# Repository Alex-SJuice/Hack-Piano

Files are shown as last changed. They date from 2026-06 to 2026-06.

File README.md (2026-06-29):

# Hack Piano

A Hackpad, in the form of a piano!

It can serve as a normal macropad too.

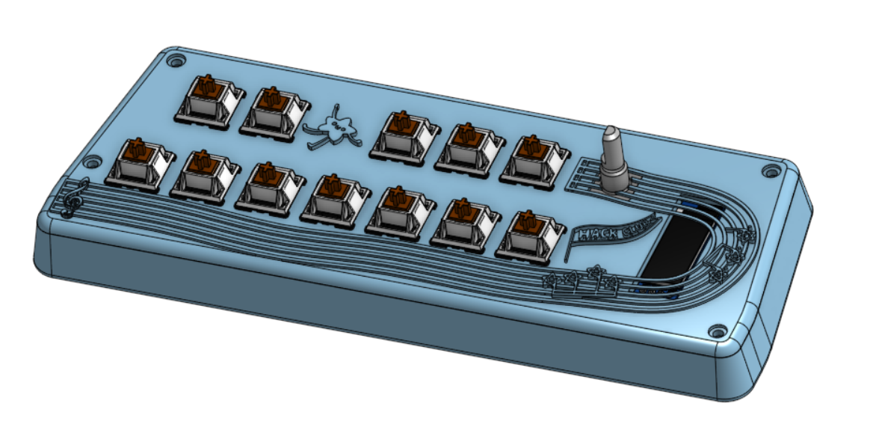
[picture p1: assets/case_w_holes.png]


## Motivation

I've wanted a MIDI keyboard for a while, and I thought this would be a decent substitute (and a fun challenge!).

This is my first ever project I've made from start to finish, with my own design, so It's very exciting!

I'm hoping to use the skills from this project in others, like my WIP 3d camera (shameless plug)

## Schematic & PCB

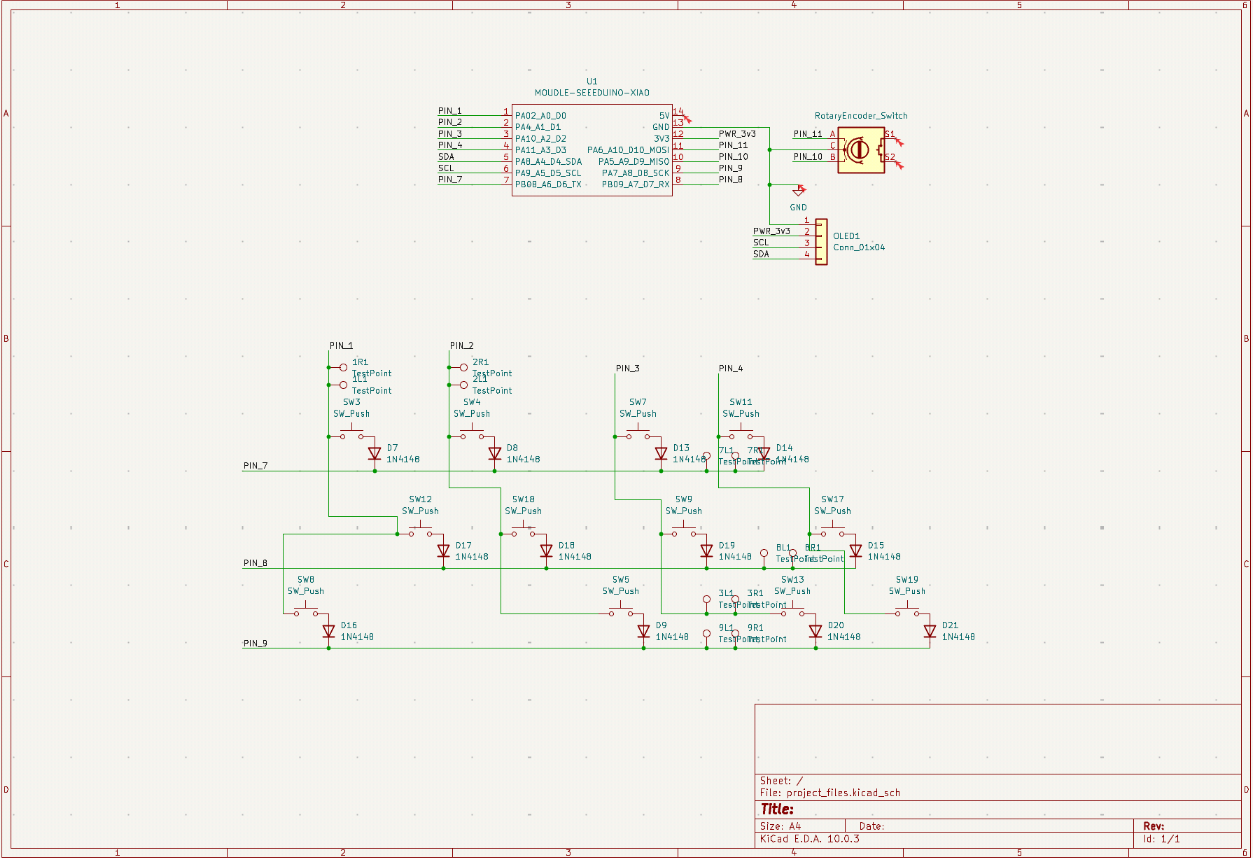
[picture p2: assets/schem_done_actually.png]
Schematic


It was difficult to align everything so the traces are nice, especially since I was forced to wire the keys in a 4x3 grid because of the number of pins

Another BIG problem was that the pcb was too wide. I decided to split the pcb in half and stack the two halves together to get the size requirements, then add breakpoints so I could assemble and solder the pcb together. Thanks to Anicetus for the idea!

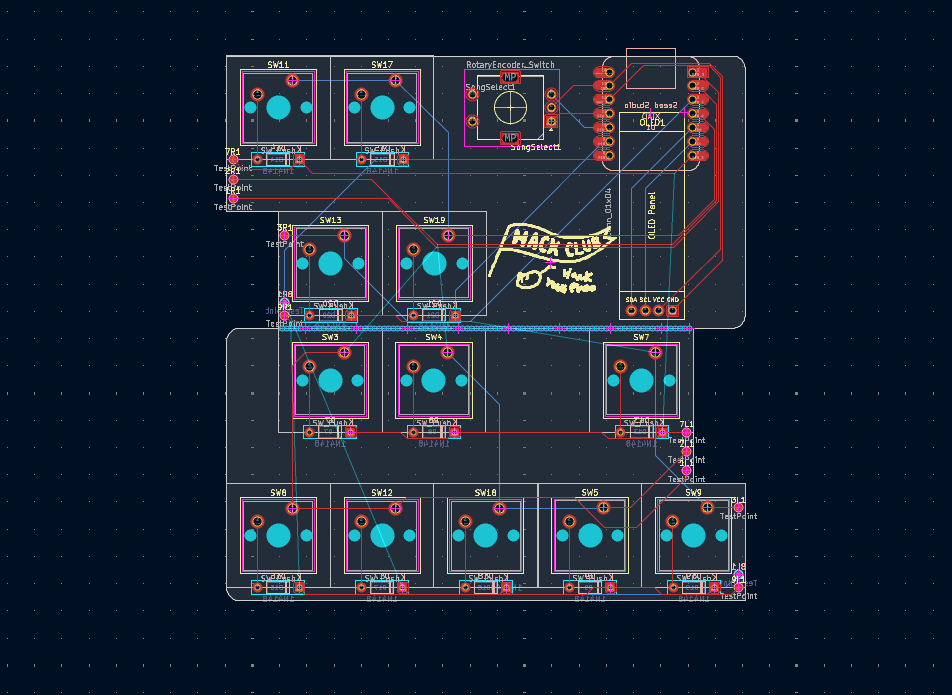
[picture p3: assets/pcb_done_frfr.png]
PCB


Final Shape:

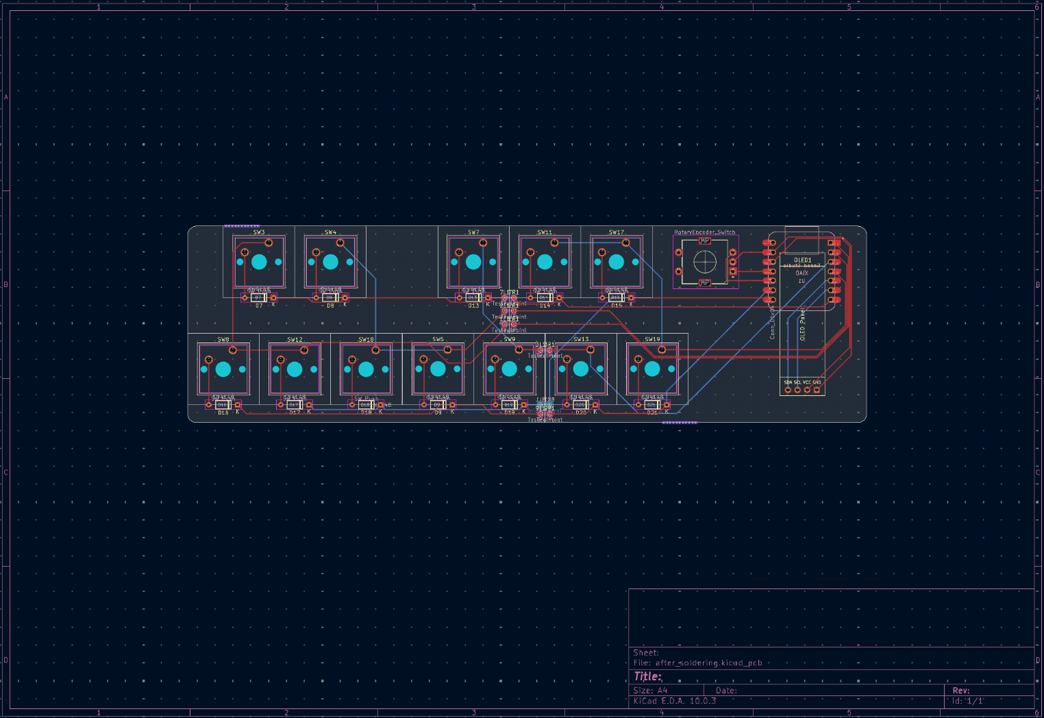
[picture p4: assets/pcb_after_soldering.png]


## Case

Oh my goodness, the case was actually horrible to work on. It mostly stems from the fact that I decided to make a bunch of small details that would be really annoying to change if say, the lid and base were different shapes the entire time. Also someone's got to burn the Onshape splines on a stake.

btw all of the overhangs are getting printed with supports (should I provide gcode in that case?)

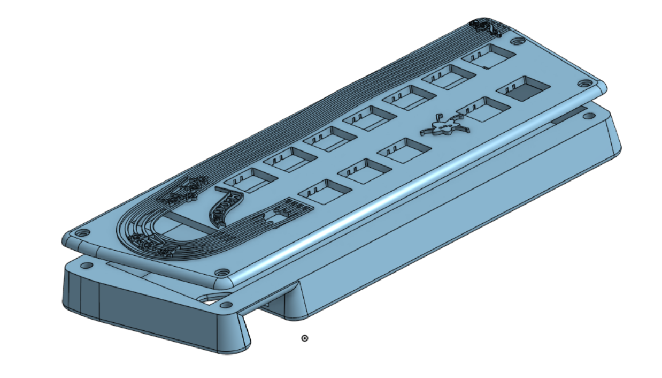
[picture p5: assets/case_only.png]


## BOM:
 - 12x Cherry MX Switches
 - 12x DSA Keycaps (optional but you can get 2u keys for the bottoms 7)
 - 4x M3x5x4 Heatset inserts
 - 4x M3x16mm screws
 - 12x 1N4148 DO-35 Diodes
 - 1x 0.91" 128x32 OLED Display
 - 1x EC11 Rotary Encoder
 - 1x XIAO RP2040
 - 1x Case (2 printed parts)

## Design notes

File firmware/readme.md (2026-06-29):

# hack_piano

*A Hackpad (courtesy of Hackclub), in the form of a piano!*

* Keyboard Maintainer: [Alex](https://github.com/Alex-SJuice)
* Hardware Supported: *The PCBs, controllers supported*
* Hardware Availability: *Links to where you can find this hardware*

Make example for this keyboard (after setting up your build environment):

    make hack_piano:default

Flashing example for this keyboard:

    make hack_piano:default:flash

See the [build environment setup](https://docs.qmk.fm/#/getting_started_build_tools) and the [make instructions](https://docs.qmk.fm/#/getting_started_make_guide) for more information. Brand new to QMK? Start with our [Complete Newbs Guide](https://docs.qmk.fm/#/newbs).

## Bootloader

Enter the bootloader in 3 ways:

* **Bootmagic reset**: Hold down the key at (0,0) in the matrix (usually the top left key or Escape) and plug in the keyboard
* **Physical reset button**: Briefly press the button on the back of the PCB - some may have pads you must short instead
* **Keycode in layout**: Press the key mapped to `QK_BOOT` if it is available

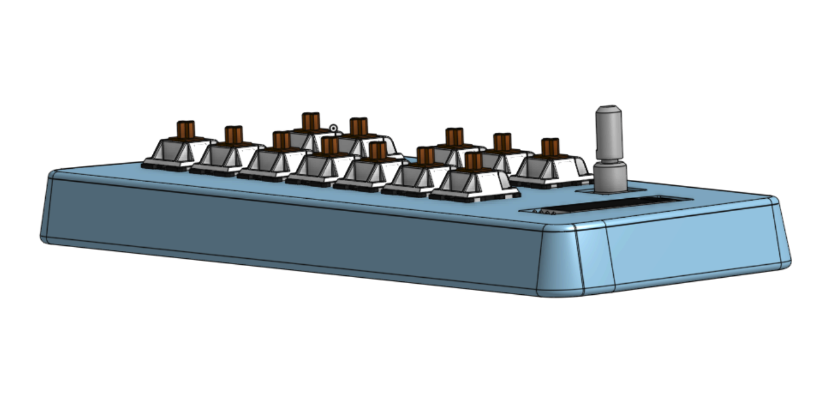
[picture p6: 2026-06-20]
assets/wip_pics/curved.png

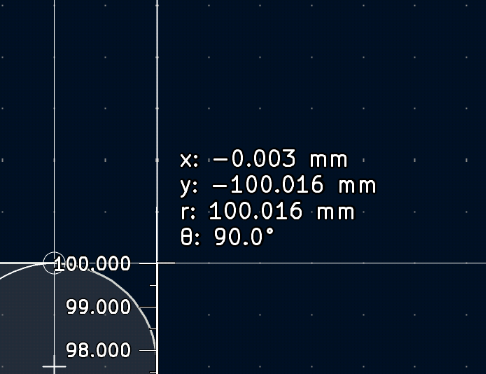
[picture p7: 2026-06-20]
assets/wip_pics/close.png

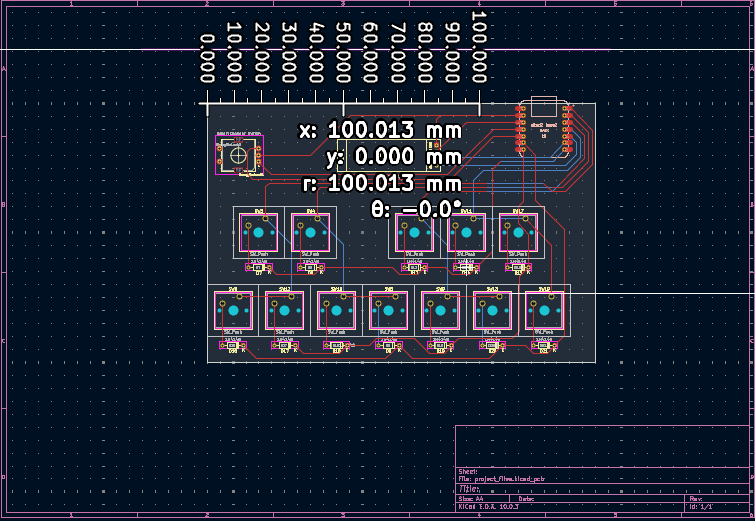
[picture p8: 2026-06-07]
assets/wip_pics/pcb_wip3.png

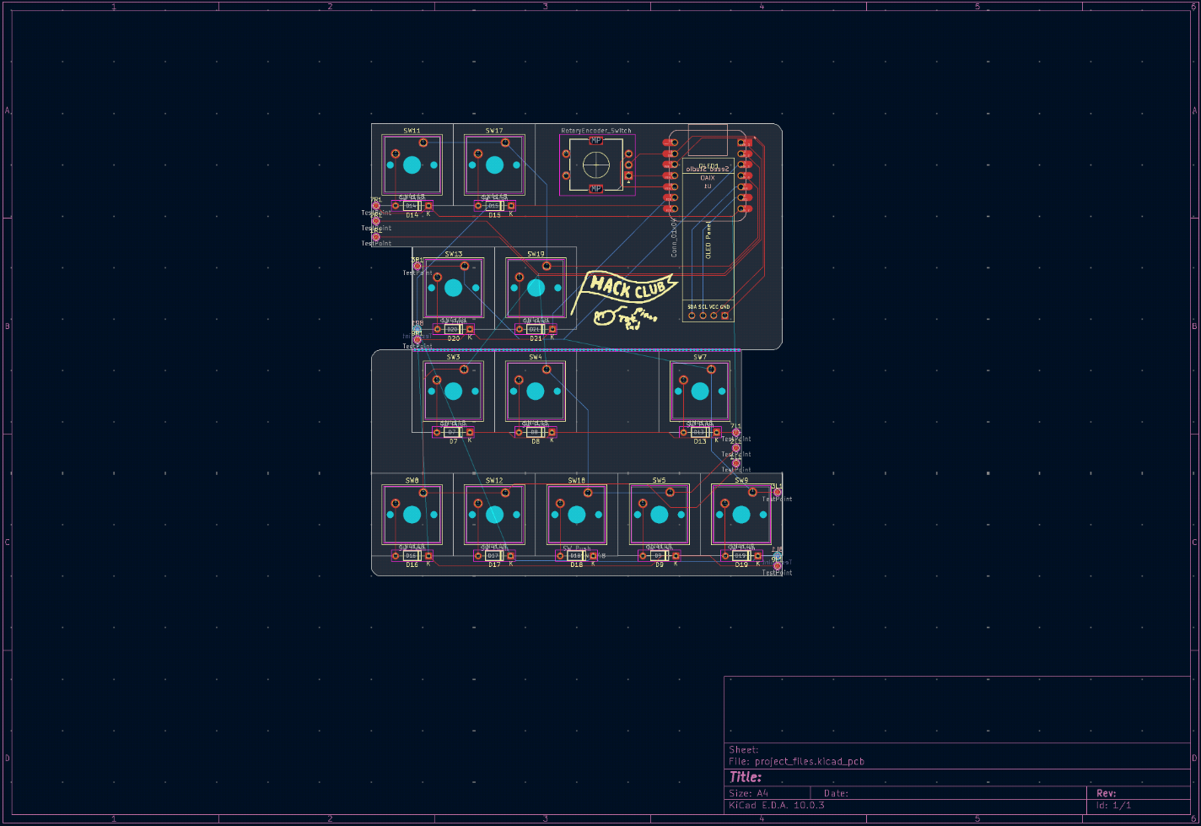
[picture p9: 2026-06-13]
assets/wip_pics/pcb_done_fr.png

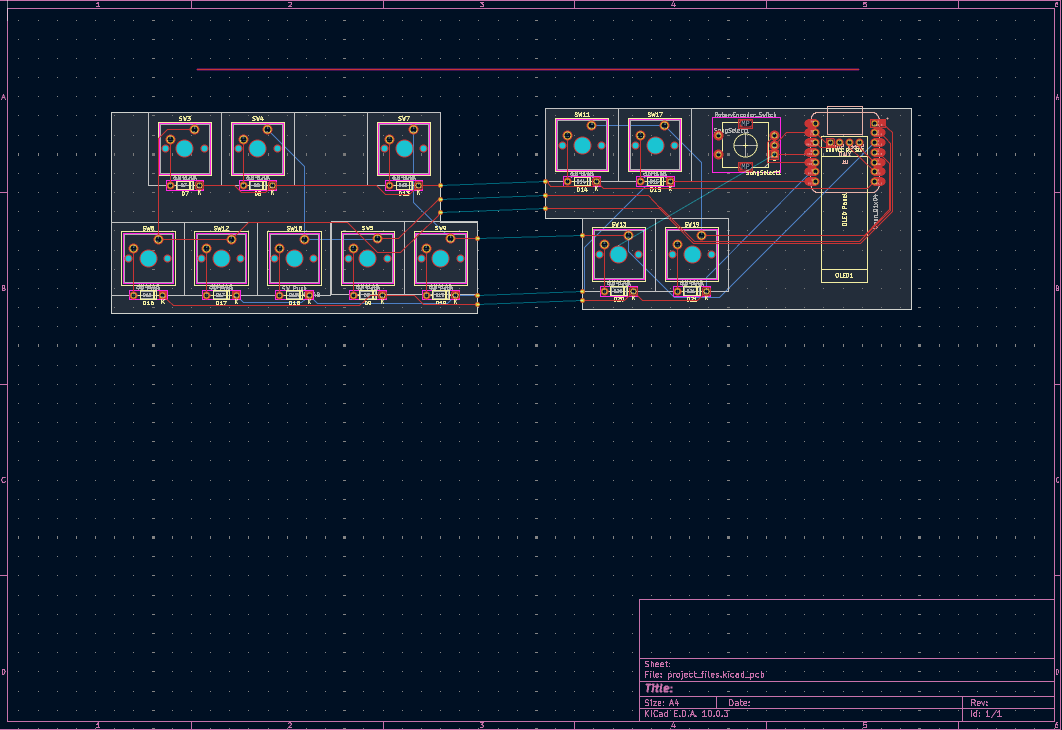
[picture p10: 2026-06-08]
assets/wip_pics/pcb_wip4.png

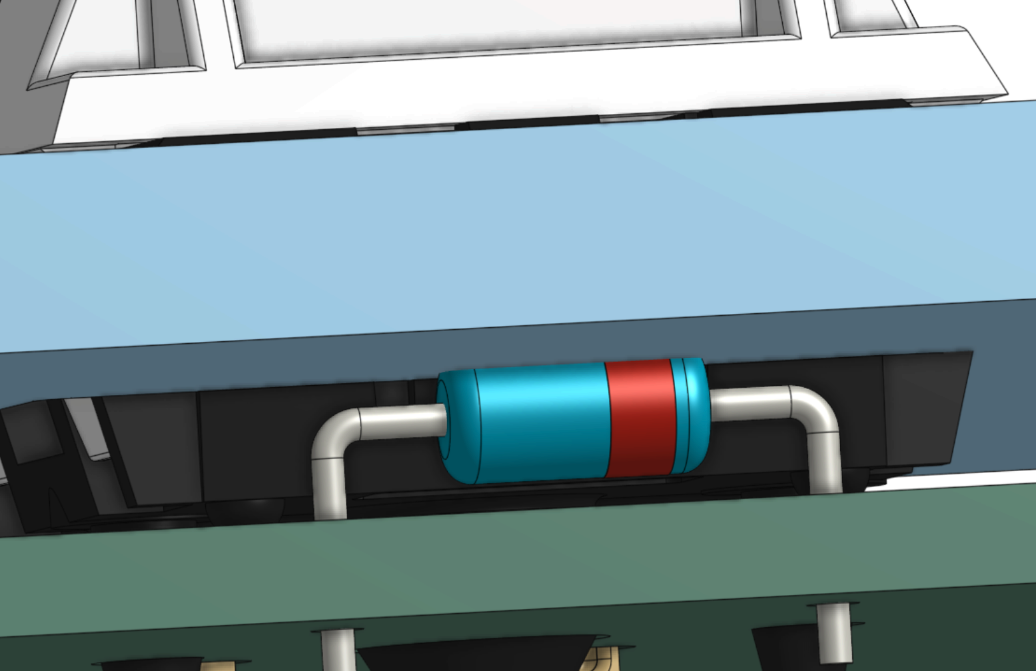
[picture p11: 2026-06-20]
assets/wip_pics/uhhhhhhh.png

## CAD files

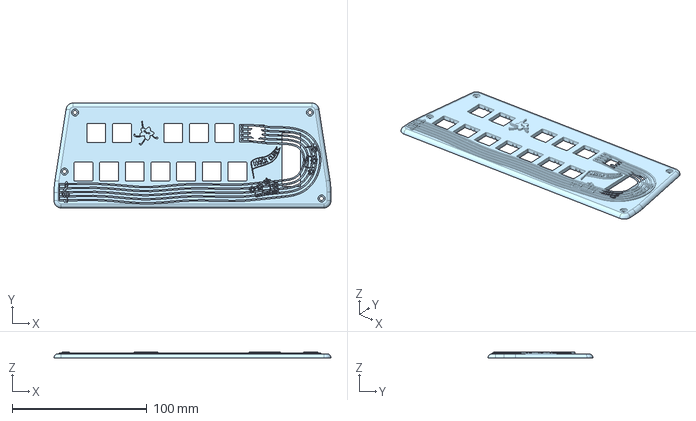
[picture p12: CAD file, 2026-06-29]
production/Lid.step
205.7 x 77.9 x 4.25 mm

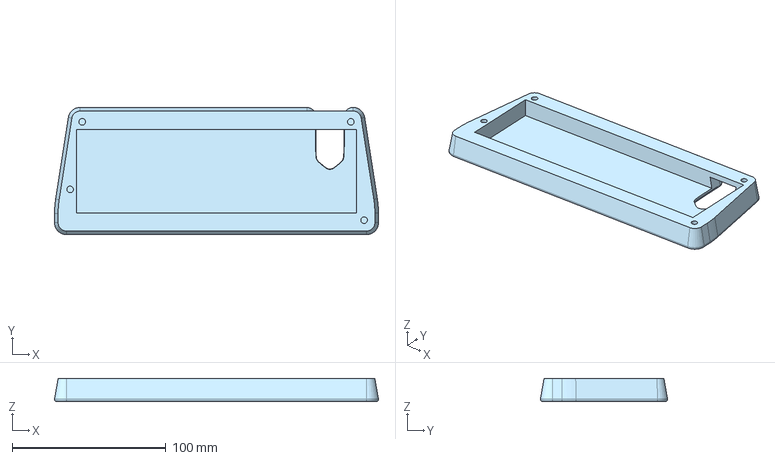
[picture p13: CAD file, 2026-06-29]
production/Base.step
210.4 x 82.6 x 15.0 mm

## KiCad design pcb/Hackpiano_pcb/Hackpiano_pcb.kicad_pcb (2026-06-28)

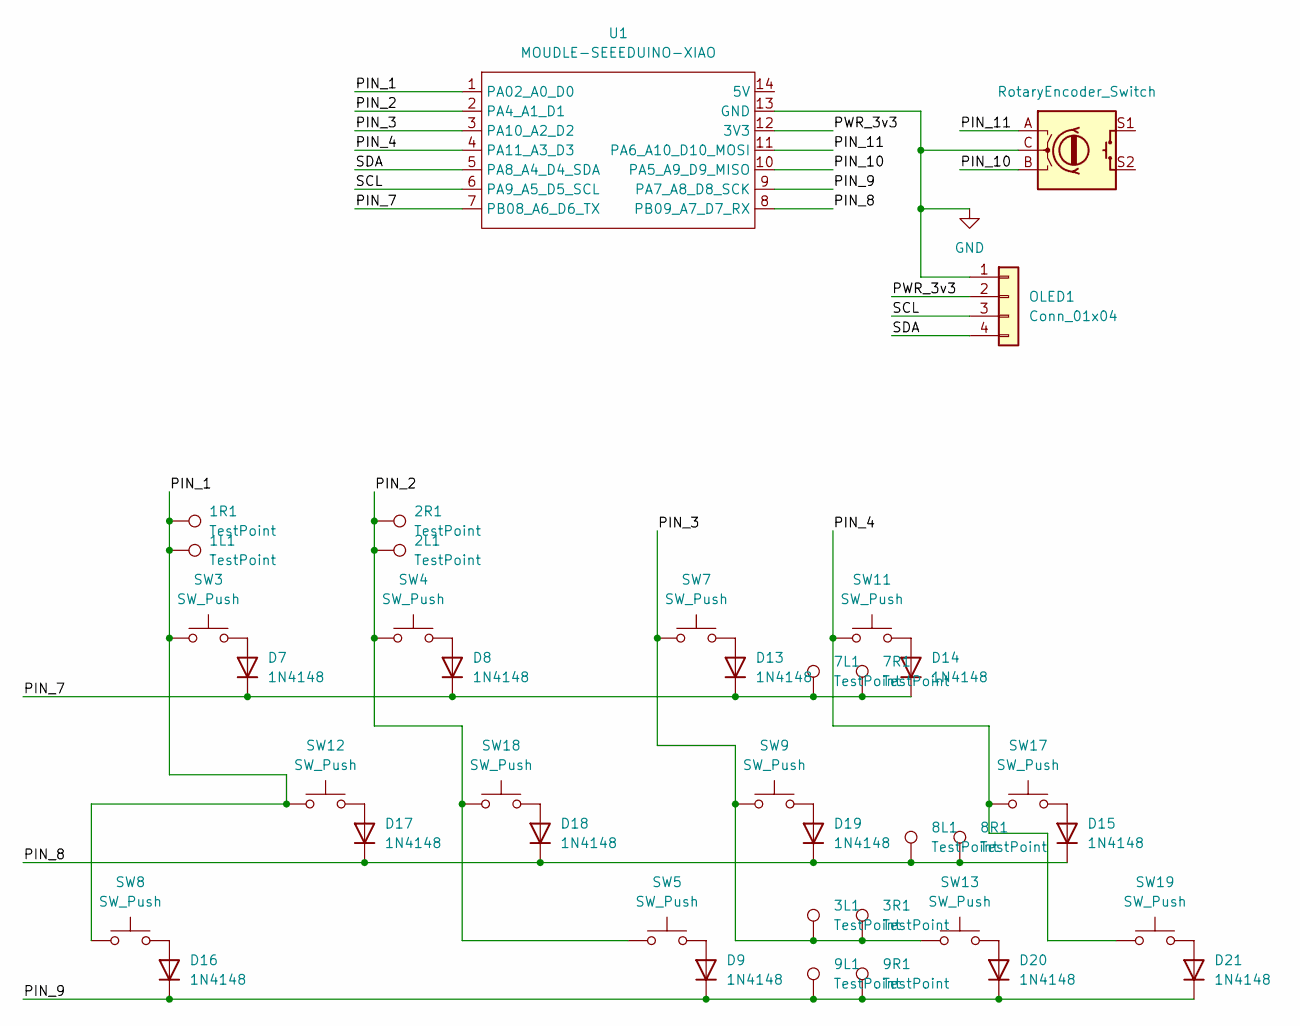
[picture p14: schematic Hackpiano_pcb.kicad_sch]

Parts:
1L1, 1R1, 2L1, 2R1, 3L1, 3R1, 7L1, 7R1, 8L1, 8R1, 9L1, 9R1: TestPoint; TestPoint_Pad_D1.0mm
D7, D8, D9, D13, D14, D15, D16, D17, D18, D19, D20, D21: 1N4148; D_DO-35_SOD27_P7.62mm_Horizontal
OLED1: Conn_01x04; SSD1306-0.91-OLED-4pin-128x32
SW3, SW4, SW5, SW7, SW8, SW9, SW11, SW12, SW13, SW17, SW18, SW19: SW_Push; SW_Cherry_MX_1.00u_PCB
SongSelect1: RotaryEncoder_Switch; RotaryEncoder_Alps_EC11E-Switch_Vertical_H20mm
U1: MOUDLE-SEEEDUINO-XIAO; XIAO-Generic-Hybrid-14P-2.54-21X17.8MM

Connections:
/PIN_1: 1L1.1 (1_1), 1R1.1 (1_1), SW3.1, SW8.1, SW12.1, U1.1 (PA02_A0_D0)
/PIN_2: 2L1.1 (1_1), 2R1.1 (1_1), SW4.1, SW5.1, SW18.1, U1.2 (PA4_A1_D1)
/PIN_3: 3L1.1 (1_1), 3R1.1 (1_1), SW7.1, SW9.1, SW13.1, U1.3 (PA10_A2_D2)
/PIN_4: SW11.1, SW17.1, SW19.1, U1.4 (PA11_A3_D3)
/PIN_7: 7L1.1 (1_1), 7R1.1 (1_1), D7.1 (K), D8.1 (K), D13.1 (K), D14.1 (K), U1.7 (PB08_A6_D6_TX)
/PIN_8: 8L1.1 (1_1), 8R1.1 (1_1), D15.1 (K), D17.1 (K), D18.1 (K), D19.1 (K), U1.8 (PB09_A7_D7_RX)
/PIN_9: 9L1.1 (1_1), 9R1.1 (1_1), D9.1 (K), D16.1 (K), D20.1 (K), D21.1 (K), U1.9 (PA7_A8_D8_SCK)
/PIN_10: SongSelect1.B, U1.10 (PA5_A9_D9_MISO)
/PIN_11: SongSelect1.A, U1.11 (PA6_A10_D10_MOSI)
/PWR_3v3: OLED1.2, U1.12 (3V3)
/SCL: OLED1.3, U1.6 (PA9_A5_D5_SCL)
/SDA: OLED1.4, U1.5 (PA8_A4_D4_SDA)
GND: OLED1.1, SongSelect1.C, U1.13 (GND)
unnamed: D7.2 (A), SW3.2
unnamed: D8.2 (A), SW4.2
unnamed: D9.2 (A), SW5.2
unnamed: D13.2 (A), SW7.2
unnamed: D14.2 (A), SW11.2
unnamed: D15.2 (A), SW17.2
unnamed: D16.2 (A), SW8.2
unnamed: D17.2 (A), SW12.2
unnamed: D18.2 (A), SW18.2
unnamed: D19.2 (A), SW9.2
unnamed: D20.2 (A), SW13.2
unnamed: D21.2 (A), SW19.2

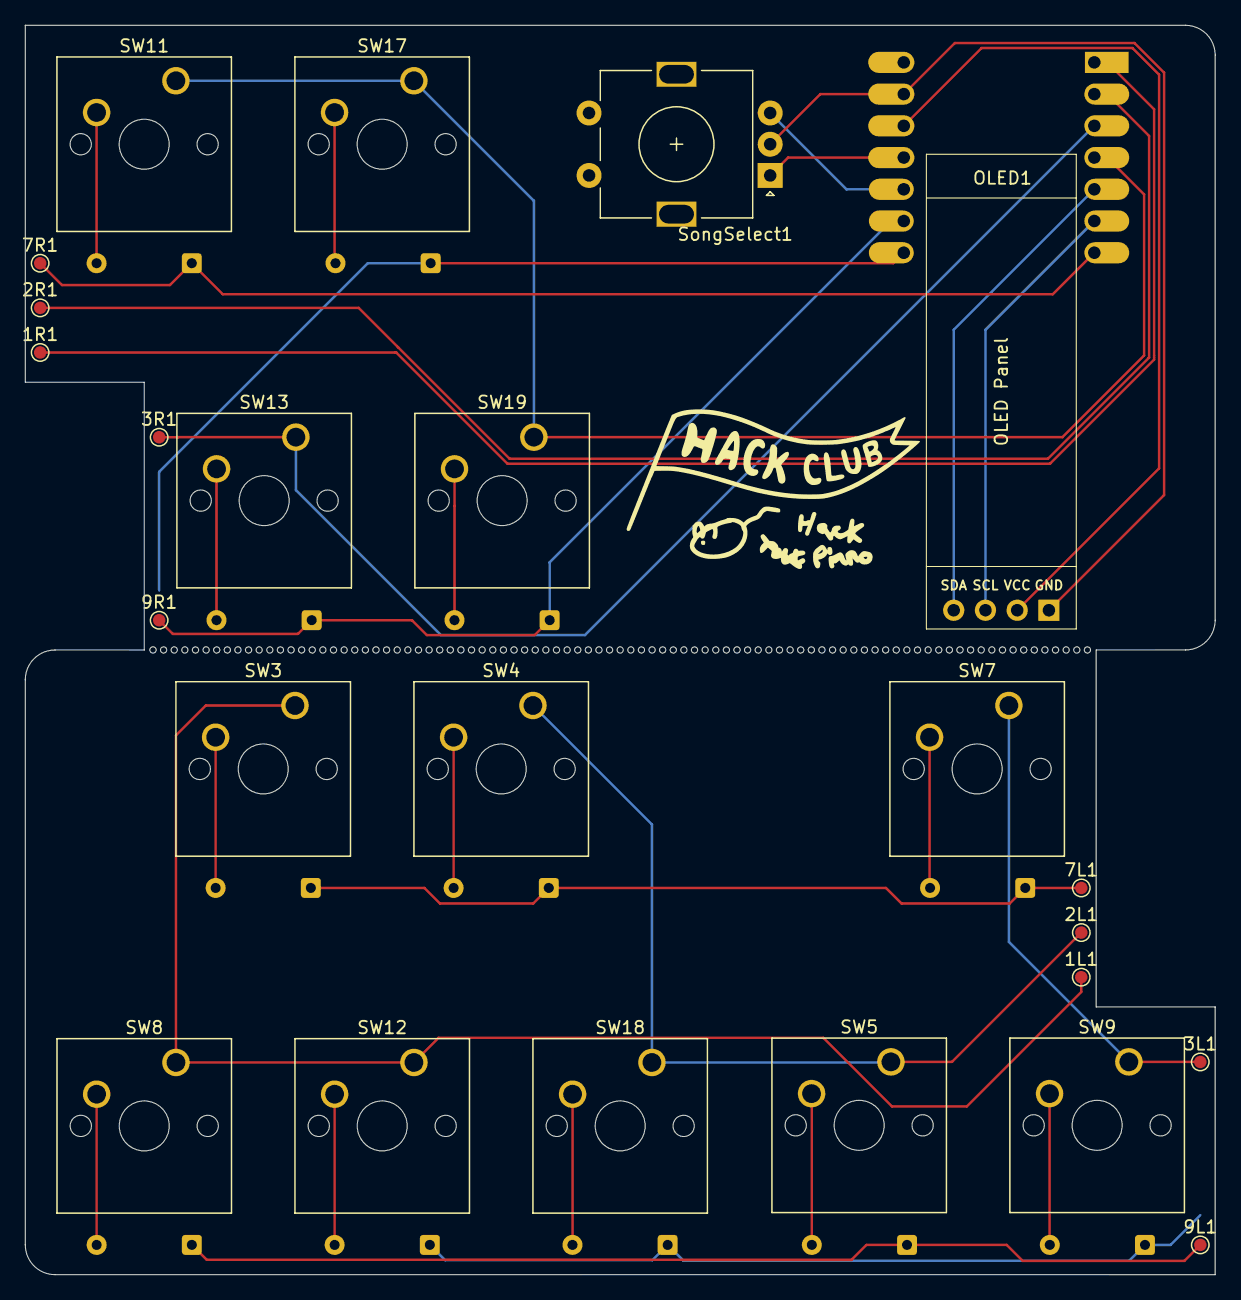
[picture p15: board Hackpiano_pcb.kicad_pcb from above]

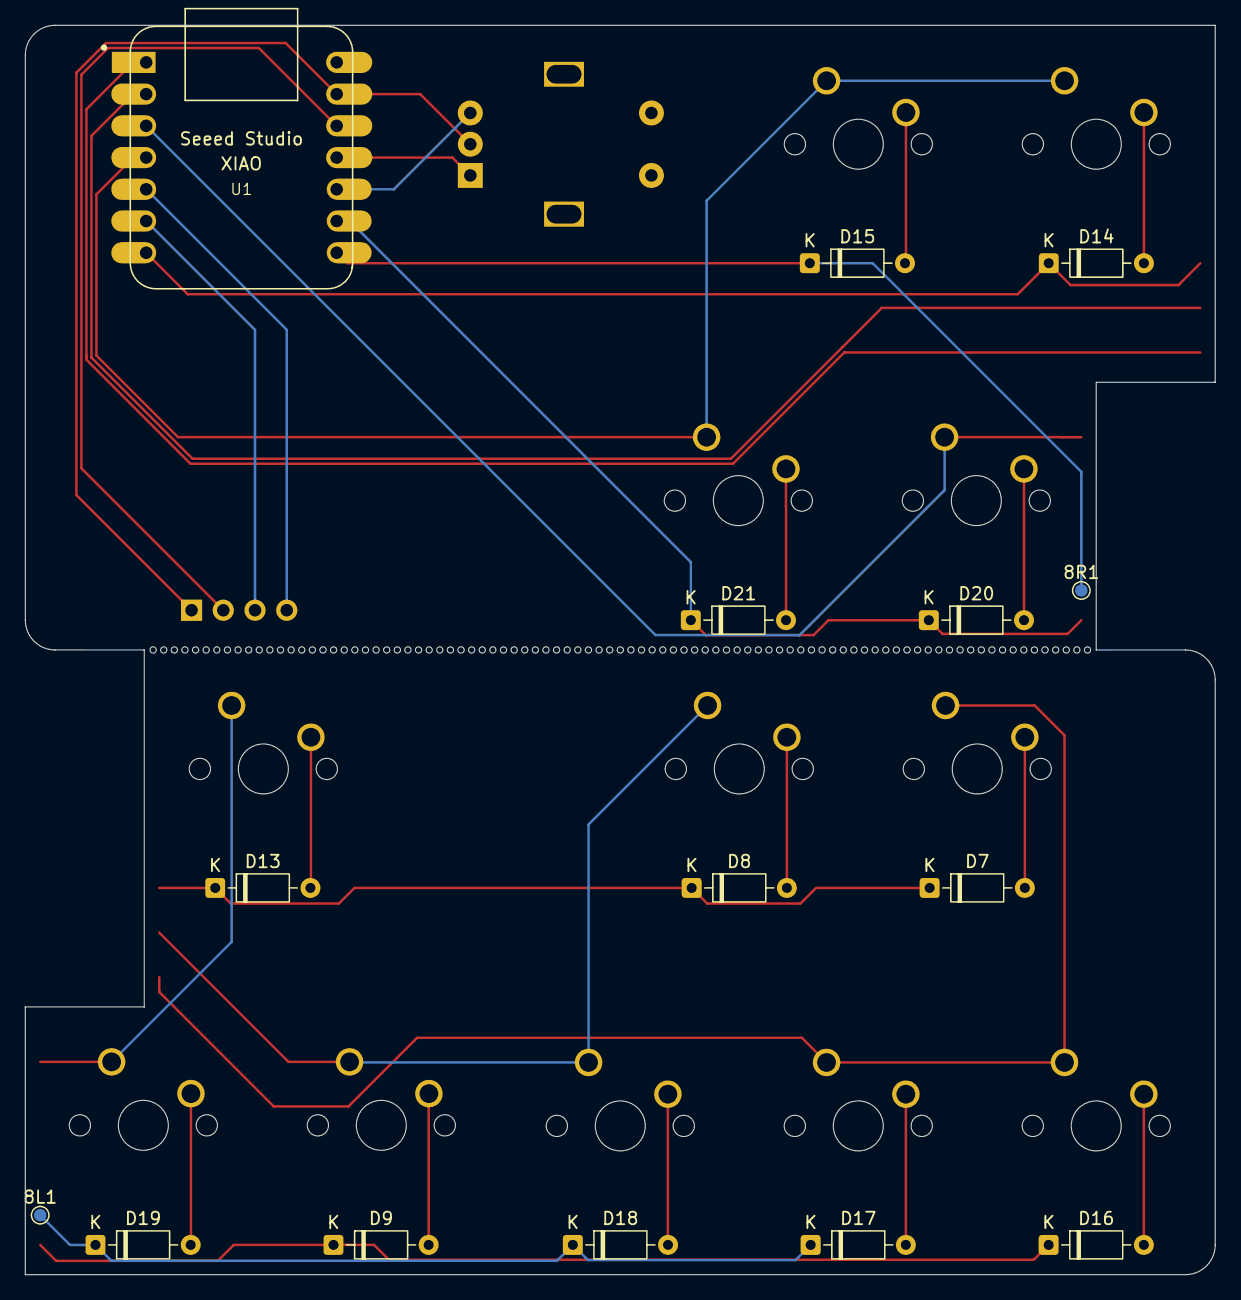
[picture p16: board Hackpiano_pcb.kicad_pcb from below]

Board: 2 copper layers, 95.3 x 100.0 mm, 39 parts (15 on the bottom side), 25 nets.

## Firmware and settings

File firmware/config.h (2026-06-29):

// Copyright 2026 Alex-SJuice (@Alex-SJuice)
// SPDX-License-Identifier: GPL-2.0-or-later

#define ENCODER_A_PINS {GP3}
#define ENCODER_B_PINS {GP4}

#define I2C_DRIVER I2CD1
#define I2C1_SDA_PIN GP6
#define I2C1_SCL_PIN GP7

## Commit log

2026-06-05 Schem done, pcb wip
    [project_files.kicad_pcb, project_files.kicad_sch]
2026-06-05 more pcb work
    [project_files.kicad_pcb]
2026-06-07 pcb done
    pcb too big
    might have to scrap the project entirely
    [project_files.kicad_pcb]
2026-06-08 new pcb design
    [project_files.kicad_pcb]
2026-06-08 pcb done maybe
    kudos anicetus
    [project_files.kicad_pcb]
2026-06-11 gerbers
    castellated holes are really expensive though so there's gonna have to be a slight redesign
    [project_files-B_Cu.gbr, project_files-B_Mask.gbr, project_files-B_Paste.gbr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]
2026-06-12 test pads
    no more castellated holes
    my wallet is saved
    [project_files.kicad_pcb, project_files.kicad_sch]
2026-06-12 forgor to save pcb
    oops
    [project_files.kicad_pcb]
2026-06-13 after solder
    and curves :)
    [after_soldering.kicad_pcb]
2026-06-13 oled centered
    with silkscreen!
    [after_soldering.kicad_pcb, project_files.kicad_pcb]
2026-06-20 lots of case work
    pcb subject to change, so no gerbers yet
    [after_soldering.kicad_pcb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]
2026-06-23 reorganization 1
    [after_soldering.kicad_pcb, project_files.kicad_pcb, project_files.kicad_sch]
2026-06-23 partial pcb path fixes
    [after_soldering.kicad_pcb, project_files.kicad_pcb]
2026-06-25 flipping diodes and stuff
    [after_soldering.kicad_pcb, project_files.kicad_pcb]
2026-06-28 hopefully I'm done
    I'm so not done bro I'm gonna have to remodel this whole thing <:(((((((((((
    [Base.stl, Hackpiano_pcb.kicad_pcb, Hackpiano_pcb.kicad_sch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]
2026-06-29 gerbers i think
    bro the firmware pmo
    [Base.step, Base.stl, Lid.step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]
